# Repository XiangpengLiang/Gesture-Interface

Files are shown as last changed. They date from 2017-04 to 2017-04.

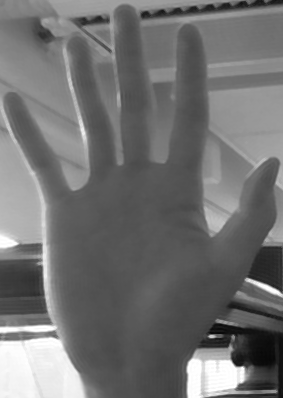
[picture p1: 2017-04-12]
image/hand2.png

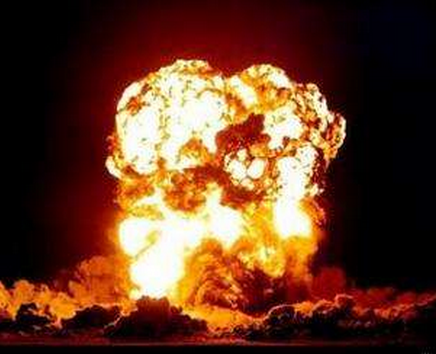
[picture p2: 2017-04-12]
image/boom.png

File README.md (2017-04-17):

Gesture Interface Glove<br>
University of Glasgow<br>
Real Time Embedded Programming: Raspberry PI Assignment
=
[Demonstration video](https://youtu.be/rbo2YH-eyuY)
=
Tutor: Bernd Porr<br>
Students: Xiangpeng Liang, Zhong Lu, Chenhan Ye
-

Introduction
-
   This project aims to attach flex sensors to the glove, and drive the sensor to deform through the bending of the finger, displaying the physical input value on the screen. After calibration, simple gesture games (Rock-Paper-Scissor) can be realized in the current system. Also, this system is suitable for exploitation for various gesture control applications.<br>
   Sampling rate: 441Hz for five sensors and 2205Hz for one sensor<br>
   Power coumption: 3.3W
 
 
Making it work
-
Hardware: Raspberry Pi B+,PCB, 5 [flex sensors](http://www.robotshop.com/uk/22-10k-flexible-sensor.html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) on a glove<br>
System: 2017-03-02-raspbian-jessie-lite<br>
Install: Git, xorg<br>
Library: bcm2835, Qwt, Qt 4.8

To clone the git repository:
-
    git clone https://github.com/pppxp/Gesture-Interface.git

To build:
-
    cd Gesture-Interaface
    qmake
    make

To run (assuming you are logged into the RPi over ssh and no X-server is running):

    startx ./Gesture

=================================

Qt is a cross platform framework for developing graphical applications, for more information please visit the links below:
* [Qt Homepage](http://qt-project.org/)
* [Qt 4.8 Class List](http://qt-project.org/doc/qt-4.8/classes.html)
* [Wikpedia](http://en.wikipedia.org/wiki/Qt_%28framework%29)
* [Signals and Slots](http://qt-project.org/doc/qt-4.8/signalsandslots.html)

Qwt is a technical widget library based on Qt, please see:
* [Qwt Hompage](http://qwt.sourceforge.net/)

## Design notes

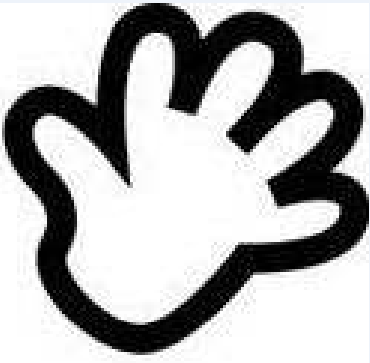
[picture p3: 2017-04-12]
image/paper.png

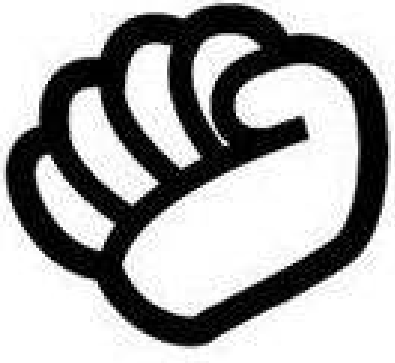
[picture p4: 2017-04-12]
image/rock.png

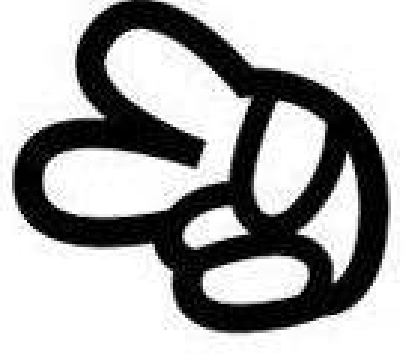
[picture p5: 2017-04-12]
image/scissor.png

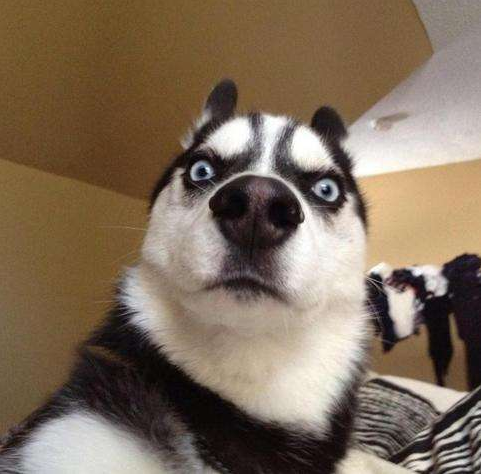
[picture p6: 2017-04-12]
image/dog.png

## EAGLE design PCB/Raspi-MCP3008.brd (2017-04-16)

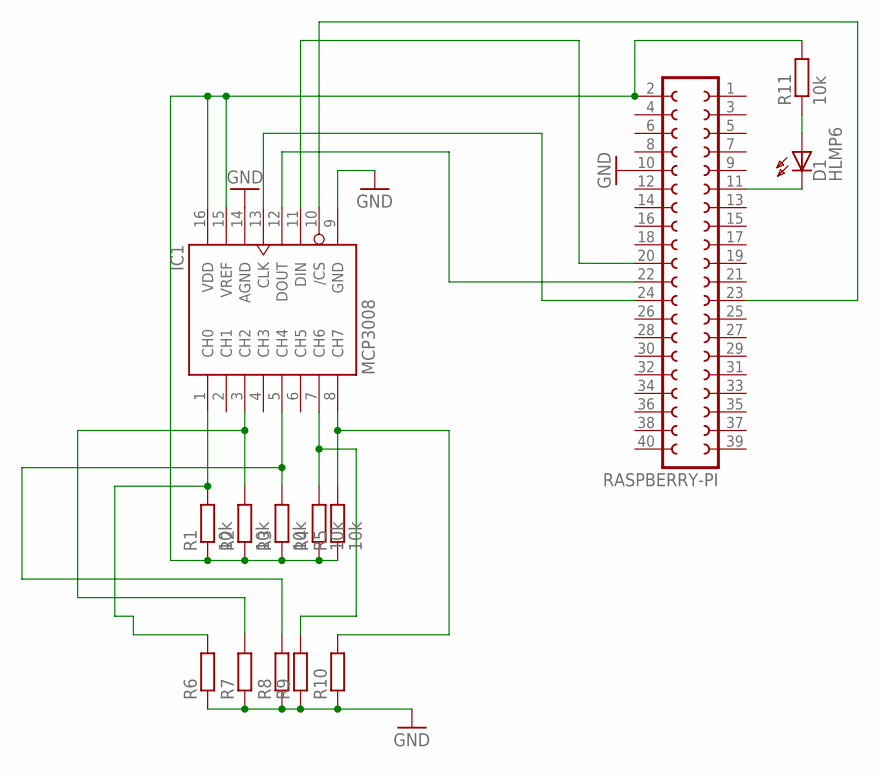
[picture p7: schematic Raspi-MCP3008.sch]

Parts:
D1: HLMP6
IC1: MCP3008; DIL16
R1, R2, R3, R4, R5, R11: 10k; 0207/10
R6, R7, R8, R9, R10: R-EU_0204/2V; 0204V
RASPBERRY-PI: FE20-2

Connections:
GND: IC1.9 (GND), IC1.14 (AGND), R6.1, R7.1, R8.1, R9.1, R10.1, RASPBERRY-PI.10
unnamed: D1.A, R11.1
unnamed: D1.K, RASPBERRY-PI.11
unnamed: IC1.13 (CLK), RASPBERRY-PI.24
unnamed: IC1.12 (DOUT), RASPBERRY-PI.22
unnamed: IC1.11 (DIN), RASPBERRY-PI.20
unnamed: IC1.10 (/CS), RASPBERRY-PI.23
unnamed: IC1.3 (CH2), R2.2, R7.2
unnamed: IC1.1 (CH0), R1.2, R6.2
unnamed: IC1.5 (CH4), R3.2, R8.2
unnamed: IC1.7 (CH6), R4.2, R9.2
unnamed: IC1.8 (CH7), R5.2, R10.2
unnamed: IC1.15 (VREF), IC1.16 (VDD), R1.1, R2.1, R3.1, R4.1, R5.1, R11.2, RASPBERRY-PI.2

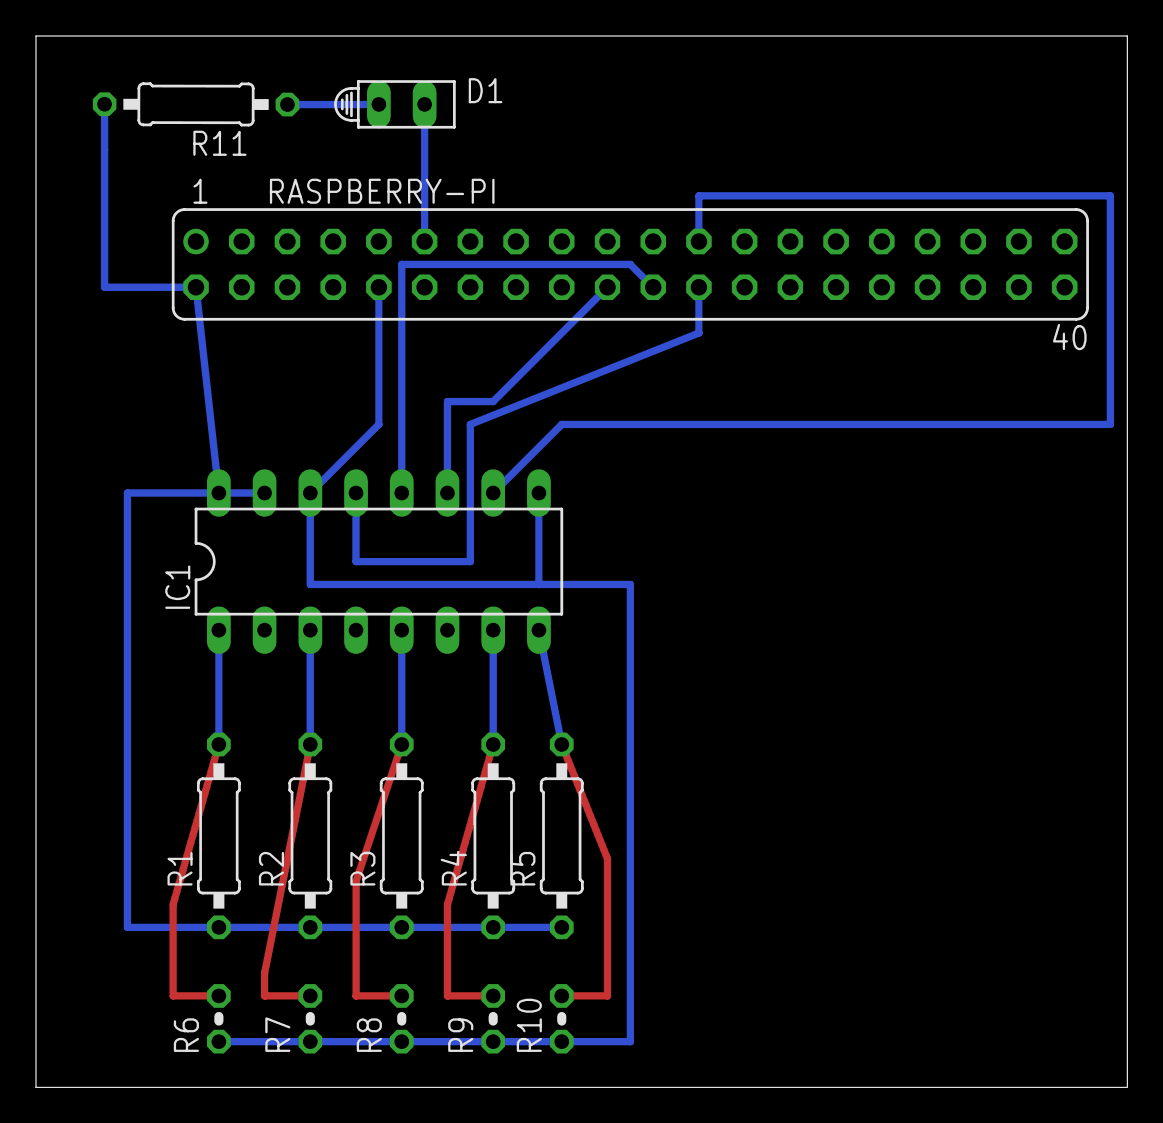
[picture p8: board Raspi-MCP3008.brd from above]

Board: 2 copper layers, 60.6 x 58.4 mm, 14 parts (0 on the bottom side), 13 nets.

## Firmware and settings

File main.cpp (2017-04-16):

// University of Glasgow
// Real Time Embedded Programming
// Raspberry PI Assignment
// Name: Xiangpeng Liang; Zhong Lu; Chenhan Ye
// Data:16/04/2017

/*
Attach the glove to the flex sensor, and drive the sensor
 to deform through the bending of the finger, displaying
the physical input value on the screen. Then, simple gesture
 games can be realized by proofreading operation within
the system.
*/

#include <window.h>
#include <QApplication>

bool Compare[5];

int main(int argc, char *argv[])
{
    QApplication app(argc, argv);

    // create the window
    Window window;
    window.showMaximized();
    window.show();
    // call the window.timerEvent function every 10 ms
    window.startTimer(10);

    // execute the application
    return app.exec();
}

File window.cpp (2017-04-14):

#include "window.h"
#include "adcreader.h"
#include <QDebug>

Window::Window()
{
    //    image1.load(":/hand2.png");

    //Set up the display components
    finger1 = new QwtThermo;
    finger2 = new QwtThermo;
    finger3 = new QwtThermo;
    finger4 = new QwtThermo;
    finger5 = new QwtThermo;

    finger1->setFillBrush( QBrush(Qt::blue) );
    finger2->setFillBrush( QBrush(Qt::red) );
    finger3->setFillBrush( QBrush(Qt::green) );
    finger4->setFillBrush( QBrush(Qt::red) );
    finger5->setFillBrush( QBrush(Qt::green) );

    finger1->setRange(2.45, 3);
    finger2->setRange(2.45, 3);
    finger3->setRange(2.45, 3);
    finger4->setRange(2.45, 3);
    finger5->setRange(2.45, 3);


    finger1->show();
    finger2->show();
    finger3->show();
    finger4->show();
    finger5->show();


    //Set up the bottons
    quit= new QPushButton("Quit", this);
    connect(quit, SIGNAL (released()), this, SLOT (handleButton()));

    Guessing= new QPushButton("Rock-paper-scissors", this);
    connect(Guessing, SIGNAL (released()), this, SLOT (openGuessing()));
    //   Guessing->setEnable(false);

    Open = new QPushButton("Open Fingers", this);
    connect(Open, SIGNAL (released()), this, SLOT (OpenFingers()));

    Close = new QPushButton("Close Fingers", this);
    connect(Close, SIGNAL (released()), this, SLOT (CloseFingers()));

    //Set up the labels
    label = new QLabel(this);
    label->setText("Please OPEN your fingers and click 'Open finger'");
    label->setWordWrap(true);
    label->adjustSize();

    QFont Ft,Ff;
    Ft.setPointSize(20);
    Ft.setPointSize(15);
    Title = new QLabel(this);
    Title->setText("Gesture Interface Glove");
    Title->setTextFormat(Qt::RichText);
    Title->setAlignment(Qt::AlignCenter);
    Title->setFont(Ft);

    Uniname = new QLabel(this);
    Uniname->setText("University of Glasgow");
    Uniname->setAlignment(Qt::AlignCenter);
    Uniname->setFont(Ft);

    author = new QLabel(this);
    author->setText("Xiangpeng Liang, Zhong Lu, Chenhan Ye");
    author->setAlignment(Qt::AlignCenter);

    Thumb = new QLabel(this);
    Thumb->setText("Thumb");
    Thumb->setAlignment(Qt::AlignBottom);
    Thumb->setFont(Ff);
    Thumb->adjustSize();
    //    Thumb->resize(100,100);

    Forefinger = new QLabel(this);
    Forefinger->setText("Forefinger");
    Forefinger->setAlignment(Qt::AlignBottom);
    Forefinger->setFont(Ff);
    Forefinger->adjustSize();

    Middlefinger = new QLabel(this);
    Middlefinger->setText("Middlefinger");
    Middlefinger->setAlignment(Qt::AlignBottom);
    Middlefinger->setFont(Ff);
    Middlefinger->adjustSize();

    Ringfinger = new QLabel(this);
    Ringfinger->setText("Ringfinger");
    Ringfinger->setAlignment(Qt::AlignBottom);
    Ringfinger->setFont(Ff);
    Ringfinger->adjustSize();

    Littlefinger = new QLabel(this);
    Littlefinger->setText("Littlefinger");
    Littlefinger->setAlignment(Qt::AlignBottom);
    Littlefinger->setFont(Ff);
    Thumb->adjustSize();



    // set up the layout
    vLayout = new QVBoxLayout;
    Buttons = new QVBoxLayout;
    titleLayout = new QVBoxLayout;
    DataDisplay = new QGridLayout;
    hLayout2 = new QHBoxLayout;


    Calibration = new QGroupBox(tr("Calibration"));
    CalibrationLayout = new QVBoxLayout;
    CalibrationLayout->addWidget(Open,4);
    CalibrationLayout->addWidget(Close,4);
    CalibrationLayout->addWidget(label,1);
    Calibration->setLayout(CalibrationLayout);

    Buttons->addWidget(Calibration);
    Buttons->addWidget(Guessing);
    Buttons->addWidget(quit);

    titleLayout->addWidget(Title);
    titleLayout->addWidget(Uniname);
    titleLayout->addWidget(author);

    DataDisplay->addWidget(Thumb,1,0);
    DataDisplay->addWidget(Forefinger,1,1);
    DataDisplay->addWidget(Middlefinger,1,2);
    DataDisplay->addWidget(Ringfinger,1,3);
    DataDisplay->addWidget(Littlefinger,1,4);

    DataDisplay->addWidget(finger1,0,0);
    DataDisplay->addWidget(finger2,0,1);
    DataDisplay->addWidget(finger3,0,2);
    DataDisplay->addWidget(finger4,0,3);
    DataDisplay->addWidget(finger5,0,4);

    hLayout2->addLayout(DataDisplay,5);
    hLayout2->addLayout(Buttons,1);


    DataDisplay->setSpacing(80);
    hLayout2->setSpacing(100);


    vLayout->addLayout(titleLayout);
    vLayout->addLayout(hLayout2);


    setLayout(vLayout);



    //Run SPI
    adcreader = new ADCreader();
    adcreader->start();
}



void Window::timerEvent( QTimerEvent * )  //Display the value and do compare every 10ms
{

    finger1->setValue(adcreader->FingerData[0]*3.3/1023);
    finger2->setValue(adcreader->FingerData[1]*3.3/1023);
    finger3->setValue(adcreader->FingerData[2]*3.3/1023);
    finger4->setValue(adcreader->FingerData[3]*3.3/1023);
    finger5->setValue(adcreader->FingerData[4]*3.3/1023);

    for (int i=0;i<5;i++){
        Compare[i]= adcreader->FingerData[i]  >  FingerThreshold[i];

        //    printf("FingerData %u = %d  \n", i,adcreader->FingerData[i]);
        //    printf("FingerThreshold %u = %d  \n", i,FingerThreshold[i]);
        //    printf("Compare %u = %d  \n\n", i,Compare[i]);

    }

}

void Window::handleButton(){

    exit(-1);
}

void Window::openGuessing()  //Open the Scissor-Rock-paper window
{
    //    this->Close();
    guessing *guessingWindow = new guessing;
    guessingWindow->showMaximized();
    guessingWindow->show();
    guessingWindow->startTimer(300);
    //    this->show();

}


void Window::OpenFingers()   //Calibration: Collect the single when fingers open
{
    for (int i=0;i<5;i++){
        OpenFingersData[i]=adcreader->FingerData[i];
    }
    label->setText("Please CLOSE your fingers and click 'Close finger'");

}

void Window::CloseFingers()  //Calibration: Collect the single when fingers close
{
    for (int i=0;i<5;i++){
        FingerThreshold[i]=(adcreader->FingerData[i]+OpenFingersData[i])/2;
        printf("CloseFingersData %u = %d  \n", i,adcreader->FingerData[i]);
        printf("OpenFingersData %u = %d  \n", i,OpenFingersData[i]);
        printf("FingerThreshold %u = %d  \n\n", i,FingerThreshold[i]);

    }

    //Make sure the Calbration is correct
    if (adcreader->FingerData[2]>OpenFingersData[2])
    {
        label->setText("Calibration sucessful");
        //       Guessing->setEnable(true);
    }
    else
    {
        label->setText("Calibration unsucessful.　Please try again, OPEN your fingers and click 'Open finger'");
    }
}



Window::~Window()
{
    // tells the thread to no longer run its endless loop
    adcreader->quit();
    // wait until the run method has terminated
    adcreader->wait();
    delete adcreader;
}




/*
void Window::paintEvent(QPaintEvent *)
{
    //void QPainter::drawPixmap(int x, int y, int width, int height, const QPixmap &pixmap)
    QPainter painter(this);
    painter.drawPixmap(10,10,200,200,image1);
}
*/

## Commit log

2017-03-07 SPI TEST
2017-03-09 Voltage Measurement
    MCP3008
2017-03-18 A voltage display programm for single Flex sensor
    Libraries:
    bcm2835
    QT
    Qwt
    RUN:
    make distclean
    qmake
    make
    sudo startx ./Gesture
    [adcreader.cpp, window.cpp]
2017-03-18 Revert "A voltage display programm for single Flex sensor"
    This reverts commit f7a173967c9b0cc1ec8b09adbeec7638fbcea93a.
    [adcreader.cpp, window.cpp]
2017-03-18 Revert "Revert "A voltage display programm for single Flex sensor""
    This reverts commit c6185949f550405a9ea1d9f6ce988926556f2b69.
    [adcreader.cpp, window.cpp]
2017-03-18 A voltage display programm for single Flex sensor
2017-04-02 Increase the number of input to 5.
    Enable 5 ADC channels, display 5 output on the interface.
2017-04-10 Fixed the bugs in sending and receiving data
    [adcreader.cpp, window.cpp]
2017-04-16 Add PCB design files
    [Raspi-MCP3008.brd, Raspi-MCP3008.sch]
